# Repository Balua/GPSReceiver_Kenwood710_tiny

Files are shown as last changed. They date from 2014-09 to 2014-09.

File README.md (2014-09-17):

GPSReceiver_Kenwood710_tiny
===========================

##GPS Receiver for Kenwood D710 - Transforms the GPS Signal into the voltage level required by the Kenwood D710.

### Features

- Input lipo battery
- Voltage Regulator from V_IN to 3.3V (GPS)
- Voltage Regulator from V_IN to 5V (MAX232)
- UBlox MAX7 GPS breakout board from AVA Supplies
- Standard through hole MAX232 with electrolitic capacitors

### PCB

- All through hole components.
- Single layer for easy prototyping -> Etching.
- Voltage Regulators standing up.

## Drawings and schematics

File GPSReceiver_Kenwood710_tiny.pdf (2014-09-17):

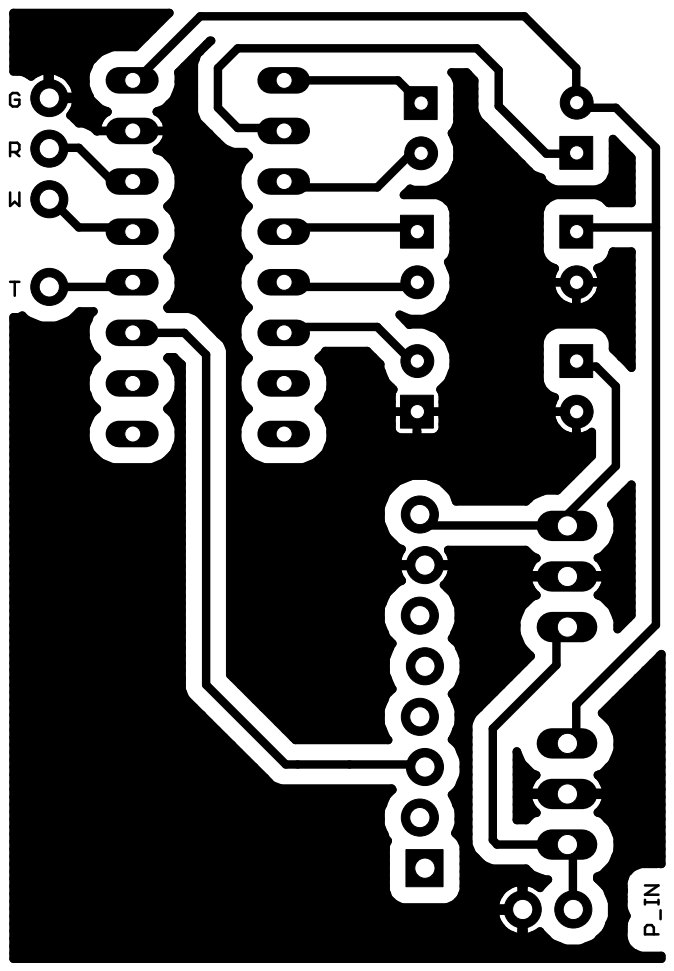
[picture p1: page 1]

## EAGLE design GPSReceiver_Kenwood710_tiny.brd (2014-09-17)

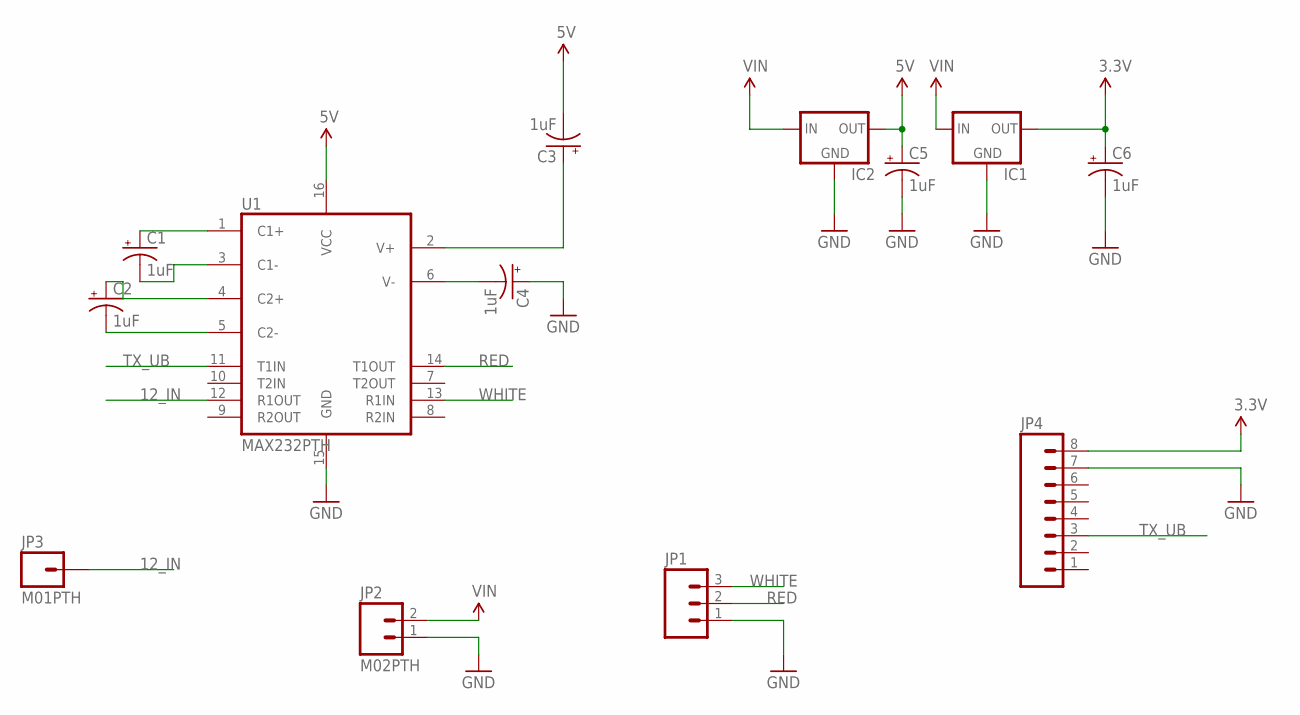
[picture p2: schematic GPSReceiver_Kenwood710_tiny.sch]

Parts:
C1, C2, C3, C4, C5, C6: 1uF; CPOL-RADIAL-10UF-25V
IC1, IC2: V_REG_78XX-TO-220; TO-220-ALT
JP1: M03PTH; 1X03
JP2: M02PTH; 1X02
JP3: M01PTH; 1X01
JP4: M08LOCK; 1X08_LOCK
U1: MAX232PTH; DIL16

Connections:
3.3V: C6.1 (+), IC1.OUT, JP4.8
5V: C3.2 (-), C5.1 (+), IC2.OUT, U1.16 (VCC)
12_IN: JP3.1, U1.12 (R1OUT)
GND: C4.1 (+), C5.2 (-), C6.2 (-), IC1.GND, IC2.GND, JP1.1, JP2.1, JP4.7, U1.15 (GND)
unnamed: C1.1 (+), U1.1 (C1+)
unnamed: C1.2 (-), U1.3 (C1-)
unnamed: C2.1 (+), U1.4 (C2+)
unnamed: C2.2 (-), U1.5 (C2-)
unnamed: C3.1 (+), U1.2 (V+)
unnamed: C4.2 (-), U1.6 (V-)
RED: JP1.2, U1.14 (T1OUT)
TX_UB: JP4.3, U1.11 (T1IN)
VIN: IC1.IN, IC2.IN, JP2.2
WHITE: JP1.3, U1.13 (R1IN)

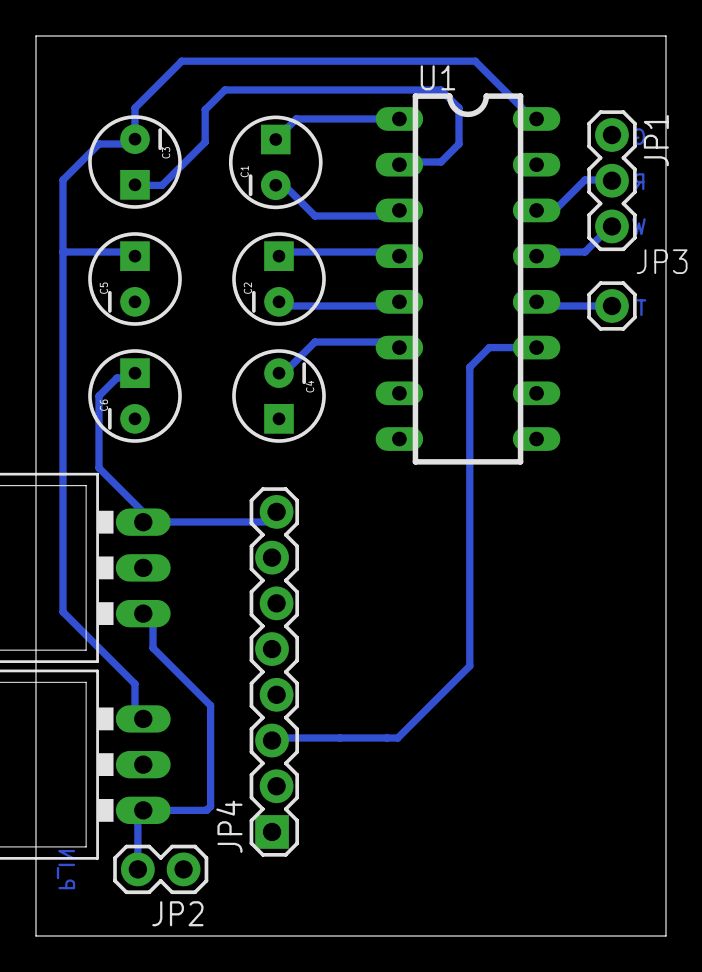
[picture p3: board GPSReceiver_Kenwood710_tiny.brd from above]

Board: 2 copper layers, 35.0 x 50.0 mm, 13 parts (0 on the bottom side), 14 nets.

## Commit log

2014-09-17 GPS Receiver for Kenwood D710
    Single Layer PCB for easy etching (smaller pcb)
    [GPSReceiver_Kenwood710_tiny.brd, GPSReceiver_Kenwood710_tiny.sch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]
2014-09-17 more clearence
    more clearence
    [GPSReceiver_Kenwood710_tiny.brd, GPSReceiver_Kenwood710_tiny.sch]

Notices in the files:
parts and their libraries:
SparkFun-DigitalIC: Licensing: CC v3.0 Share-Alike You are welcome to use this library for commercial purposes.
